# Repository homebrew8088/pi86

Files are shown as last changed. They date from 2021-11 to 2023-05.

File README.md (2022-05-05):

# pi86
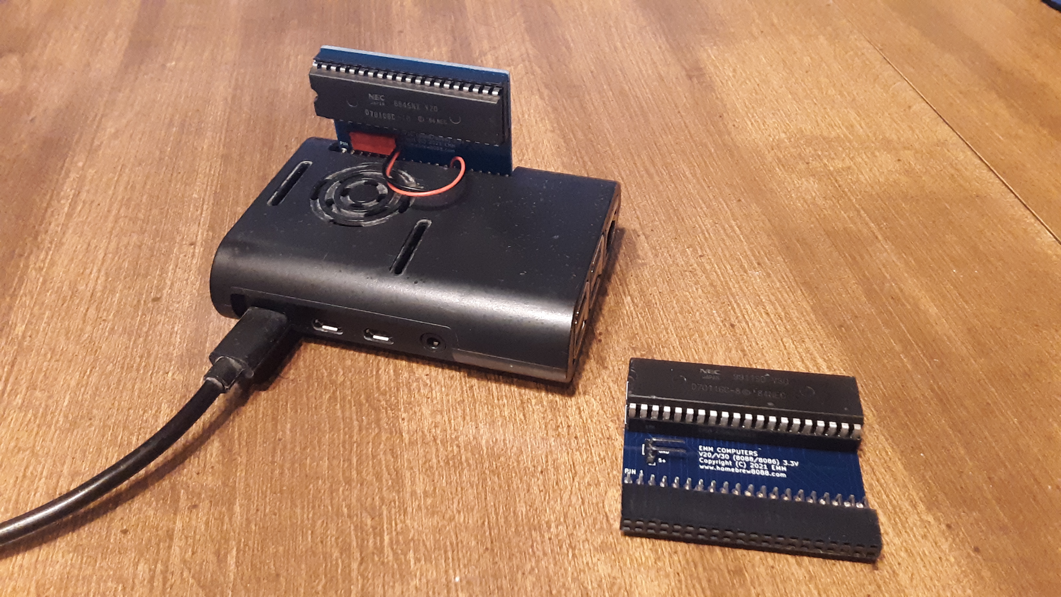
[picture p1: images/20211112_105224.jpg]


\
\
This is the code for my 8088/8086 (Really V20/V30) Raspberry Pi "hat"

https://www.homebrew8088.com/home/raspberry-pi-second-project

The code is fairly simple and easy to modify. Basically the Raspberry PI toggles the Clock then reads the Control Bus and then provides the 8088 what it is requesting. It will read the ALE pin and save the address then provide the proper Memory or IO Read/Write.  

Disadvantages:  

The speed, the processor is only running at about 0.3 MHz the best I could calculate.  But on the flip side the drive read writes are very fast because the memory is virtual on raspberry pi.

Not all 8088/8086 Processors will work. The power is connected to the 3.3v pin on the PI. Most NEC V20/V30's will operate 3V - 7V so this is not problem.   

I have written a c library that helps with interfacing the 8088 PCB.  I have also begun to develop a GUI window that emulates CGA/VGA graphics 

**I tested this with a fresh install of Raspberry PI os and it ran just fine.**

Open Terminal

git clone https://github.com/homebrew8088/pi86.git

sudo apt-get update    

sudo apt-get upgrade

sudo apt-get install gcc build-essential libsdl2-dev

sudo apt-get install nasm

git clone https://github.com/WiringPi/WiringPi.git

cd WiringPi

git pull origin

./build

cd ..

cd pi86

cd v20 (or v30)

sudo chmod +x pi86  (or pi86.)

./pi86

*** This is experimental use at your own risk. 

This current build runs very stable. I have left it running for seveal hours and came back and it was still running just fine. I encourage you to download the source code to the projects and give them a try and make modification.

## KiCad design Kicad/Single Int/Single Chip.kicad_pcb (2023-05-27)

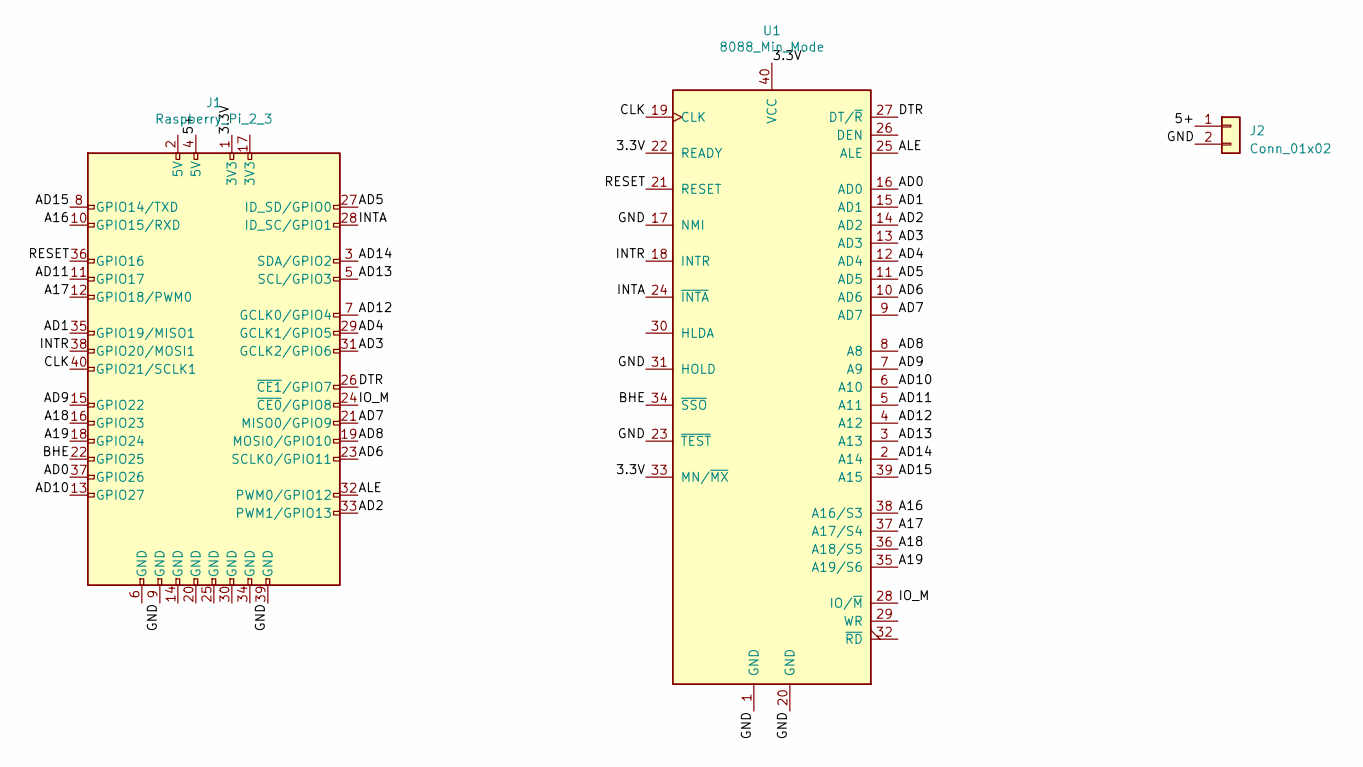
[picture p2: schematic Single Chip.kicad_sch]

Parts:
J1: Raspberry_Pi_2_3; PinHeader_2x20_P2.54mm_Vertical
J2: Conn_01x02; PinHeader_1x02_P2.54mm_Vertical
U1: 8088_Min_Mode; DIP-40_W15.24mm

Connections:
/3.3V: J1.1 (3V3), U1.22 (READY), U1.33 (MN/~MX), U1.40 (VCC)
/5+: J1.4 (5V), J2.1
/A16: J1.10 (GPIO15/RXD), U1.38 (A16/S3)
/A17: J1.12 (GPIO18/PWM0), U1.37 (A17/S4)
/A18: J1.16 (GPIO23), U1.36 (A18/S5)
/A19: J1.18 (GPIO24), U1.35 (A19/S6)
/AD0: J1.37 (GPIO26), U1.16 (AD0)
/AD1: J1.35 (GPIO19/MISO1), U1.15 (AD1)
/AD2: J1.33 (PWM1/GPIO13), U1.14 (AD2)
/AD3: J1.31 (GCLK2/GPIO6), U1.13 (AD3)
/AD4: J1.29 (GCLK1/GPIO5), U1.12 (AD4)
/AD5: J1.27 (ID_SD/GPIO0), U1.11 (AD5)
/AD6: J1.23 (SCLK0/GPIO11), U1.10 (AD6)
/AD7: J1.21 (MISO0/GPIO9), U1.9 (AD7)
/AD8: J1.19 (MOSI0/GPIO10), U1.8 (A8)
/AD9: J1.15 (GPIO22), U1.7 (A9)
/AD10: J1.13 (GPIO27), U1.6 (A10)
/AD11: J1.11 (GPIO17), U1.5 (A11)
/AD12: J1.7 (GCLK0/GPIO4), U1.4 (A12)
/AD13: J1.5 (SCL/GPIO3), U1.3 (A13)
/AD14: J1.3 (SDA/GPIO2), U1.2 (A14)
/AD15: J1.8 (GPIO14/TXD), U1.39 (A15)
/ALE: J1.32 (PWM0/GPIO12), U1.25 (ALE)
/BHE: J1.22 (GPIO25), U1.34 (~SSO)
/CLK: J1.40 (GPIO21/SCLK1), U1.19 (CLK)
/DTR: J1.26 (~CE1/GPIO7), U1.27 (DT/~R)
/GND: J1.9 (GND), J1.39 (GND), J2.2, U1.1 (GND), U1.17 (NMI), U1.20 (GND), U1.23 (~TEST), U1.31 (HOLD)
/INTA: J1.28 (ID_SC/GPIO1), U1.24 (~INTA)
/INTR: J1.38 (GPIO20/MOSI1), U1.18 (INTR)
/IO_M: J1.24 (~CE0/GPIO8), U1.28 (IO/~M)
/RESET: J1.36 (GPIO16), U1.21 (RESET)

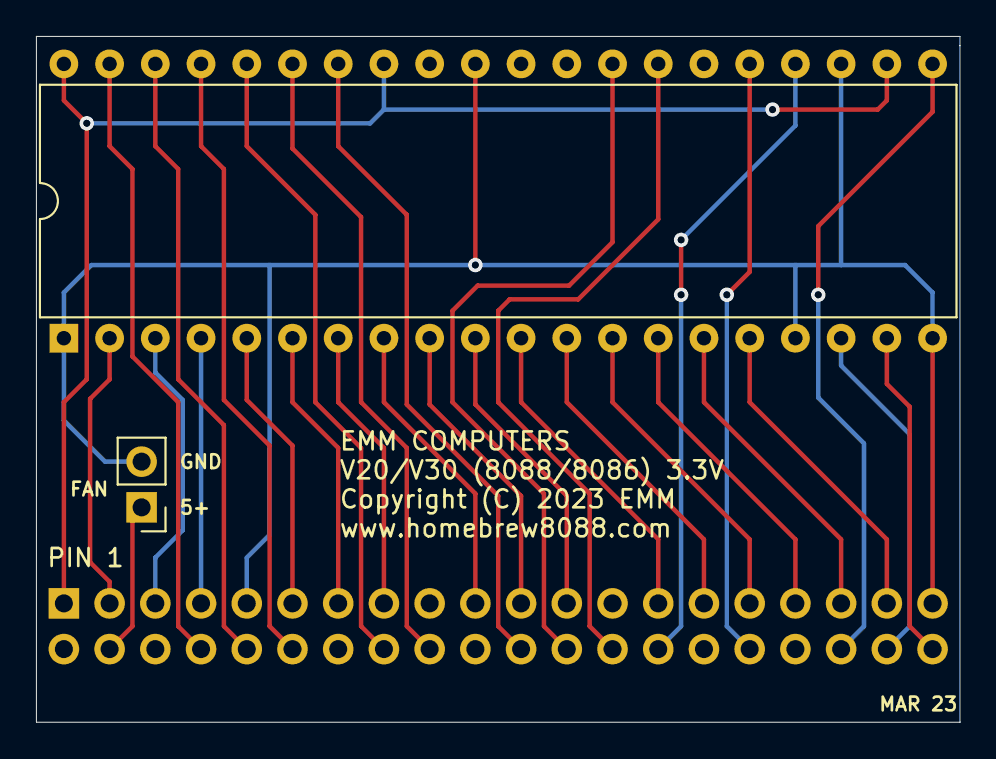
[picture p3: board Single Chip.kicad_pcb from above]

Board: 2 copper layers, 51.3 x 38.1 mm, 3 parts (1 on the bottom side), 31 nets.

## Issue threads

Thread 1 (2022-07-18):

Is there a schematic for V30?

cctsao1008, 2022-07-18:
Would you please kindly provide the schematic in pdf, thank you very much.

homebrew8088, 2022-07-18:
What is available on github is what I have for the project.

cctsao1008, 2022-07-18:
Got it, Thank you.

homebrew8088, 2022-07-20:
I have added the Kicad files to the github repository. You may find what
you're looking for there.
https://github.com/homebrew8088/pi86/tree/main/Kicad/Single%20Int

On Tue, Jul 19, 2022 at 10:49 AM cctsao1008 ***@***.***>
wrote:

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

cctsao1008, 2022-07-21:
test gpio speed in mmap()

Jetson Nano

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

homebrew8088, 2022-07-21:
I have never tested where as I don't have the equipment. The read out your showing is what I have suspected for a couple of years. 250KHz and not exactly a nice even constant cycle.

cctsao1008, 2022-07-21:
Change the Linux kernel to the PREEMPT_RT kernel

REF :
1. Setting up Realtime Kernel on Jetson
https://orenbell.com/?p=436

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

'''
.....

#define MY_PRIORITY (49) /* we use 49 as the PRREMPT_RT use 50
                            as the priority of kernel tasklets
                            and interrupt handler by default */

int main(int argc, char **argv)
{
    int val;
	int i, ret;
    static void *basePINMUX, *baseCFG, *baseCNF;
    volatile GPIO_CNF *pin40;
    volatile uint32_t *pinmux40;
    volatile uint32_t *pincfg40;
    struct sched_param param;

    /* Declare ourself as a real time task */

    param.sched_priority = MY_PRIORITY;

	if(sched_setscheduler(0, SCHED_FIFO, &param) == -1) {
        perror("sched_setscheduler failed");
        exit(-1);
    }
...
'''

cctsao1008, 2022-07-24:
I am going to use the ODYSSEY STM32MP157C instead of the Jetson Nano, The STM32MP157 includes dual Cortex A7(650Mhz) and has a Cortex M4(209Mhz) as the co-processor.
[ ODYSSEY STM32MP157C](https://wiki.seeedstudio.com/ODYSSEY-STM32MP157C)

I plan to use the Cortex to drive the V30 and Cortex A7 uses the PRMsg to communicate to it.

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

homebrew8088, 2022-07-24:
How well does it work?

On Sun, Jul 24, 2022 at 11:40 AM cctsao1008 ***@***.***>
wrote:

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

cctsao1008, 2022-07-25:
I do not know why you do not drive the CLK pin of V30 by an oscillator and the raspberry pi controls the READY pin of the V30 to handle the bus traffic.

BR CCTSAO

cctsao1008, 2022-07-26:
> How well does it work?
> […](#)
> On Sun, Jul 24, 2022 at 11:40 AM cctsao1008 ***@***.***> wrote: Reopened #1 <#1>. — Reply to this email directly, view it on GitHub <[#1 (comment)](https://github.com/homebrew8088/pi86/issues/1#event-7051691812)>, or unsubscribe <https://github.com/notifications/unsubscribe-auth/APIMBJ7QYZROV5KBZQ5FUETVVV5XFANCNFSM533VIVUQ> . You are receiving this because you commented.Message ID: ***@***.***>

I am porting it, the partial code of the pi86 needs to be moved to the M4 part. I will share my progress here.

homebrew8088, 2022-10-11:
It did not work any faster than just the chip on a card. The bottle neck is
the Raspberry PI's GPIO read write speed.

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

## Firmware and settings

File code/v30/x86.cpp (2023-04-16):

#include "x86.h"

unsigned char RAM[0x100000];
unsigned char IO[0x10000];
bool IRQ0_Flag = 0;
bool IRQ1_Flag = 0;
void IRQ0()
{
   IRQ0_Flag = true;
   digitalWrite (PIN_INTR, HIGH); 
}
void IRQ1()
{
   IRQ1_Flag = true;
   digitalWrite (PIN_INTR, HIGH); 
}
char Read_Interrupts()
{
   char intr = IRQ0_Flag;
   intr = intr + (IRQ1_Flag << 1);
   return intr;
}
//////////////////////////////
//System Bus
///////////////////////////////

int Read_Address()
{
   int Address;
   Address = digitalRead(AD0);
   Address = Address + (digitalRead(AD1) << 1);
   Address = Address + (digitalRead(AD2) << 2);
   Address = Address + (digitalRead(AD3) << 3);
   Address = Address + (digitalRead(AD4) << 4);
   Address = Address + (digitalRead(AD5) << 5);
   Address = Address + (digitalRead(AD6) << 6);
   Address = Address + (digitalRead(AD7) << 7);
   Address = Address + (digitalRead(A8) << 8);
   Address = Address + (digitalRead(A9) << 9);
   Address = Address + (digitalRead(A10) << 10);
   Address = Address + (digitalRead(A11) << 11);
   Address = Address + (digitalRead(A12) << 12);
   Address = Address + (digitalRead(A13) << 13);
   Address = Address + (digitalRead(A14) << 14);
   Address = Address + (digitalRead(A15) << 15);
   Address = Address + (digitalRead(A16) << 16);
   Address = Address + (digitalRead(A17) << 17);
   Address = Address + (digitalRead(A18) << 18);
   Address = Address + (digitalRead(A19) << 19);
   return Address;
}
//Reads the IO_M, RD, WR pins
char Read_Control_Bus()
{
	  char Control_Bus;
	  Control_Bus = digitalRead(PIN_DTR);
	  Control_Bus = Control_Bus + (digitalRead(PIN_IO_M) << 1);
	  Control_Bus = Control_Bus + (digitalRead(PIN_INTA) << 2);
	  return Control_Bus;
}
//Reads the selected Memory Bank, High/Low 8086 only
char Read_Memory_Bank()
{
	  char Memory_Bank;
	  Memory_Bank = digitalRead(AD0);
	  Memory_Bank = Memory_Bank + (digitalRead(PIN_BHE) << 1);
	  return Memory_Bank;
}
//Sets the Data Port direction for read and writes 
void Data_Bus_Direction_8088_IN()
{
    pinMode (AD0, INPUT);  
    pinMode (AD1, INPUT);
    pinMode (AD2, INPUT);
    pinMode (AD3, INPUT);
    pinMode (AD4, INPUT);
    pinMode (AD5, INPUT);
    pinMode (AD6, INPUT);
    pinMode (AD7, INPUT);
}
void Data_Bus_Direction_8088_OUT()
{
    pinMode (AD0, OUTPUT);  
    pinMode (AD1, OUTPUT);
    pinMode (AD2, OUTPUT);
    pinMode (AD3, OUTPUT);
    pinMode (AD4, OUTPUT);
    pinMode (AD5, OUTPUT);
    pinMode (AD6, OUTPUT);
    pinMode (AD7, OUTPUT);
}
void Data_Bus_Direction_8086_IN()
{
    pinMode (AD0, INPUT);  
    pinMode (AD1, INPUT);
    pinMode (AD2, INPUT);
    pinMode (AD3, INPUT);
    pinMode (AD4, INPUT);
    pinMode (AD5, INPUT);
    pinMode (AD6, INPUT);
    pinMode (AD7, INPUT);
    
    pinMode (A8, INPUT);  
    pinMode (A9, INPUT);
    pinMode (A10, INPUT);
    pinMode (A11, INPUT);
    pinMode (A12, INPUT);
    pinMode (A13, INPUT);
    pinMode (A14, INPUT);
    pinMode (A15, INPUT);
}
void Data_Bus_Direction_8086_OUT()
{
    pinMode (AD0, OUTPUT);  
    pinMode (AD1, OUTPUT);
    pinMode (AD2, OUTPUT);
    pinMode (AD3, OUTPUT);
    pinMode (AD4, OUTPUT);
    pinMode (AD5, OUTPUT);
    pinMode (AD6, OUTPUT);
    pinMode (AD7, OUTPUT);
   
    pinMode (A8, OUTPUT);  
    pinMode (A9, OUTPUT);
    pinMode (A10, OUTPUT);
    pinMode (A11, OUTPUT);
    pinMode (A12, OUTPUT);
    pinMode (A13, OUTPUT);
    pinMode (A14, OUTPUT);
    pinMode (A15, OUTPUT);
}

//Writes Data to Data Port 0-7
void Write_To_Data_Port_0_7(char Byte)
{
   digitalWrite (AD0, Byte & 1); 
   digitalWrite (AD1,(Byte >> 1) & 1); 
   digitalWrite (AD2, (Byte >> 2) & 1); 
   digitalWrite (AD3, (Byte >> 3) & 1); 
   digitalWrite (AD4, (Byte >> 4) & 1); 
   digitalWrite (AD5, (Byte >> 5) & 1); 
   digitalWrite (AD6, (Byte >> 6) & 1); 
   digitalWrite (AD7, (Byte >> 7) & 1); 
}
//Writes Data to Data Port 8-15 8086 only
void Write_To_Data_Port_8_15(char Byte)
{
   digitalWrite (A8, Byte & 1); 
   digitalWrite (A9,(Byte >> 1) & 1); 
   digitalWrite (A10, (Byte >> 2) & 1); 
   digitalWrite (A11, (Byte >> 3) & 1); 
   digitalWrite (A12, (Byte >> 4) & 1); 
   digitalWrite (A13, (Byte >> 5) & 1); 
   digitalWrite (A14, (Byte >> 6) & 1); 
   digitalWrite (A15, (Byte >> 7) & 1); 
}
//Reads Data to Data Port 0-7
char Read_From_Data_Port_0_7()
{
   char ret;
   ret = digitalRead(AD0);
   ret = ret + (digitalRead(AD1) << 1);
   ret = ret + (digitalRead(AD2) << 2);
   ret = ret + (digitalRead(AD3) << 3);
   ret = ret + (digitalRead(AD4) << 4);
   ret = ret + (digitalRead(AD5) << 5);
   ret = ret + (digitalRead(AD6) << 6);
   ret = ret + (digitalRead(AD7) << 7);
   return ret;
}
//Reads Data to Data Port 8-15 8086 only
char Read_From_Data_Port_8_15()
{
   char ret;
   ret = digitalRead(A8);
   ret = ret + (digitalRead(A9) << 1);
   ret = ret + (digitalRead(A10) << 2);
   ret = ret + (digitalRead(A11) << 3);
   ret = ret + (digitalRead(A12) << 4);
   ret = ret + (digitalRead(A13) << 5);
   ret = ret + (digitalRead(A14) << 6);
   ret = ret + (digitalRead(A15) << 7);
   return ret;
}
//Clicks the CLK pin 
void CLK()
{
   digitalWrite (PIN_CLK, HIGH);
   digitalWrite (PIN_CLK, HIGH);
   digitalWrite (PIN_CLK, HIGH);
   digitalWrite (PIN_CLK, HIGH);
   digitalWrite (PIN_CLK, HIGH);
   digitalWrite (PIN_CLK, HIGH);

   digitalWrite (PIN_CLK, HIGH);
   digitalWrite (PIN_CLK, HIGH);
   digitalWrite (PIN_CLK, HIGH);
   digitalWrite (PIN_CLK, HIGH);
   digitalWrite (PIN_CLK, HIGH);
   digitalWrite (PIN_CLK, HIGH);

   digitalWrite (PIN_CLK, LOW);   
   digitalWrite (PIN_CLK, LOW);
   digitalWrite (PIN_CLK, LOW);
   digitalWrite (PIN_CLK, LOW);
   digitalWrite (PIN_CLK, LOW);
   digitalWrite (PIN_CLK, LOW);
   
   digitalWrite (PIN_CLK, LOW);
   digitalWrite (PIN_CLK, LOW);
   digitalWrite (PIN_CLK, LOW);
   digitalWrite (PIN_CLK, LOW);
   digitalWrite (PIN_CLK, LOW);
   digitalWrite (PIN_CLK, LOW);
}

//Sets up Raspberry PI pins in the begining 
void Setup()
{
   Stop_Flag = false;
   wiringPiSetup();

   pinMode (PIN_CLK, OUTPUT);
   pinMode (PIN_RESET, OUTPUT);
   pinMode (PIN_ALE, INPUT);
   pinMode (PIN_IO_M, INPUT);
   pinMode (PIN_DTR, INPUT);
   pinMode (PIN_BHE, INPUT);

   pinMode (PIN_INTR, OUTPUT);
   pinMode (PIN_INTA, INPUT);
   digitalWrite (PIN_INTR, LOW);
   
   pinMode (AD0, INPUT);  
   pinMode (AD1, INPUT);
   pinMode (AD2, INPUT);
   pinMode (AD3, INPUT);
   pinMode (AD4, INPUT);
   pinMode (AD5, INPUT);
   pinMode (AD6, INPUT);
   pinMode (AD7, INPUT);

   pinMode (A8, INPUT);  
   pinMode (A9, INPUT);
   pinMode (A10, INPUT);
   pinMode (A11, INPUT);
   pinMode (A12, INPUT);
   pinMode (A13, INPUT);
   pinMode (A14, INPUT);
   pinMode (A15, INPUT);

   pinMode (A16, INPUT);
   pinMode (A17, INPUT);
   pinMode (A18, INPUT);
   pinMode (A19, INPUT);
}
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

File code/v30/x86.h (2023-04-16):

#ifndef X86_H
#define X86_H

#define V20 	88
#define V30 	86 

#define PIN_CLK   29
#define PIN_RESET 27
#define PIN_ALE   26
#define PIN_IO_M  10
#define PIN_DTR   11
#define PIN_BHE   6

#define PIN_INTR  28
#define PIN_INTA  31

#define AD0   25
#define AD1   24
#define AD2   23
#define AD3   22
#define AD4   21
#define AD5   30
#define AD6   14
#define AD7   13

#define A8    12
#define A9    3
#define A10   2
#define A11   0
#define A12   7
#define A13   9
#define A14   8
#define A15   15

#define A16   16
#define A17   1
#define A18   4 
#define A19   5

#include <wiringPi.h>
#include <string>
#include <thread>
#include <unistd.h>
#include <fstream> 

using namespace std;

static bool Stop_Flag;


void Reset();	
void Start(int Processor);
void Load_Bios(string Bios_file);
//Memory
void Write_Memory_Array(unsigned long long int Address, char code_for_8088[], int Length);
void Read_Memory_Array(unsigned long long int Address, char* char_Array, int Length);
void Write_Memory_Byte(unsigned long long int Address, char byte_for_8088);
char Read_Memory_Byte(unsigned long long int Address);		
void Write_Memory_Word(unsigned long long int Address, unsigned short int word_for_8088);
//IO
void Write_IO_Array(unsigned long long int Address, char code_for_8088[], int Length);
void Read_IO_Array(unsigned long long int Address, char* char_Array, int Length);
void Write_IO_Byte(unsigned long long int Address, char byte_for_8088);
char Read_IO_Byte(unsigned long long int Address);
void Write_IO_Word(unsigned long long int Address, unsigned short int word_for_8088);

//INT

void IRQ0();
void IRQ1();
#endif

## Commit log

2022-07-20 Added Kicad files
    [Single Chip-B_Cu.gbr, Single Chip-B_Mask.gbr, Single Chip-B_Paste.gbr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]
2023-02-14 Update PCB
    [Single Chip-B_Cu.gbr, Single Chip-B_Mask.gbr, Single Chip-B_Paste.gbr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]
2023-02-14 Fixed Schematic and PCB
    [Single Chip-B_Cu.gbr, Single Chip-B_Mask.gbr, Single Chip-B_Paste.gbr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]
2023-05-27 switched back to socket
    [Single Chip-B_Cu.gbr, Single Chip-B_Mask.gbr, Single Chip-B_Paste.gbr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]

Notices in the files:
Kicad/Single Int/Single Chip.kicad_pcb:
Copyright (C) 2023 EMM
